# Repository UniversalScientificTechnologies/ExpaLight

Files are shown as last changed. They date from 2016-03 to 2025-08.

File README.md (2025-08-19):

 [Facebook](https://www.facebook.com/expalight)

# ExpaLight

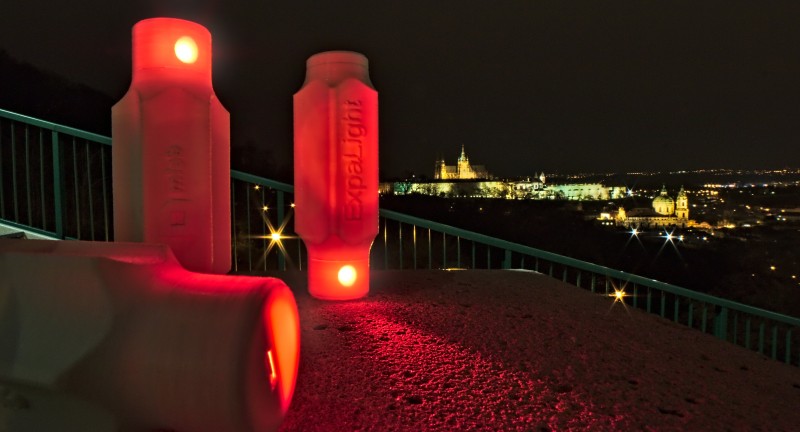
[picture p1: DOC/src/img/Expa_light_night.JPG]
ExpaLight 2017


**ExpaLight** is a red LED flashlight powered by a supercapacitor, designed especially for astronomical observations. The project originated for use during observation nights at summer astronomical schools at the observatory. Thanks to its robust and open-source design, ExpaLight is suitable for both amateur and professional users.

## Technical Parameters

| Parameter | Value |
| --- | --- |
| Stored energy | 350 J |
| Light duration | \~10 h |
| Charging time | < 50 s (typ.), max. 2 min |
| Charging indication | Green LED off at 80% voltage |
| Charging interface  | MicroUSB, ≤500 mA |
| Housing | 3D-printed PLA, durable, water-resistant |
| Light Source | High-efficiency red LED |

## Key Features

* **Supercapacitor energy storage** (350 J)
* **Light duration:** up to 10 hours
* **Fast charging:** typically under 50 seconds, max. 2 minutes from full discharge
* **Charging indication:** green LED turns off at \~80% voltage
* **Durable 3D-printed housing**, mechanically and water resistant
* **High-efficiency red LED**, optimized for dark adaptation of the human eye
* **No batteries needed**, USB charging (microUSB)
* **Open-source and repairable**

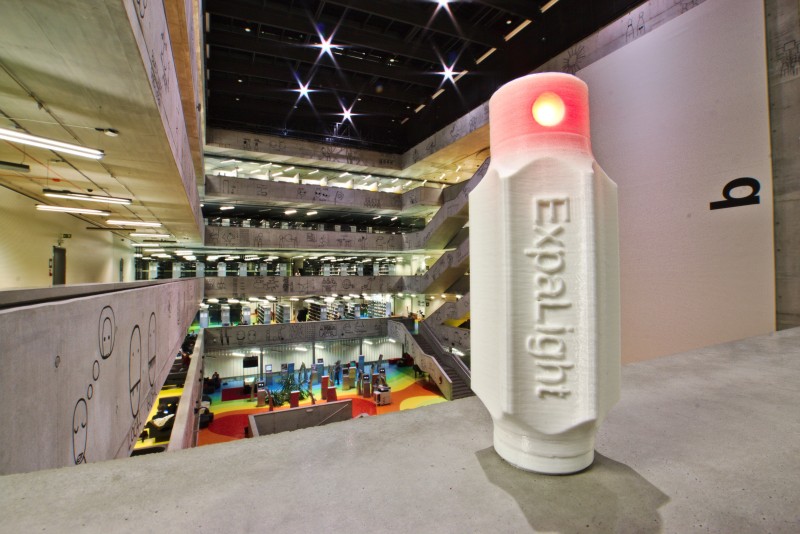
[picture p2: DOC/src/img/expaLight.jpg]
ExpaLight version 2017 ExpaLight


ExpaLight remains an active project despite repository inactivity. The design was made to withstand years of usage.

[Product manual – Czech version](/DOC/ExpaLight_navod.pdf)

## Why red light?

Astronomers use red light because it preserves the dark adaptation of the human eye, making it ideal for observing the night sky.

## Usage

* Can be placed **horizontally** (ideal for writing into observation logs)
* Can stand **vertically** with LED up or down
* Can be recharged while in use
* Works even when permanently connected to a charger

## Maintenance

* Clean with cloth and mild soapy water
* Do not wash under running water or immerse in liquids
* Avoid abrasive tools to prevent scratching the housing

## Frequently Asked Questions

**Do I need to switch it off?**
No. The flashlight has no mechanical switch. It shines until fully discharged, then you recharge it via USB.

**Why this shape?**
The hexagonal body prevents rolling, ensures stable positioning on surfaces, and supports versatile use (e.g. headlamp attachment in future).

**Can I leave it charging permanently?**
Yes. The electronics are designed to handle permanent connection safely.

**What happens if it is fully discharged?**
Nothing. Unlike battery-based lamps, the supercapacitor can be fully discharged without degradation.

**Can I use a mobile charger?**
Yes. Any standard microUSB charger (5V, ≤500 mA) or USB port will work. Some smart chargers may fail due to low current draw — in that case, use another charger.

## Availability

You can purchase ExpaLight at [Tindie](https://www.tindie.com/products/10265/) or contact us directly at **[sale@ust.cz](mailto:sale@ust.cz)**.

## Contributions

ExpaLight is an open-source hardware project. Suggestions and improvements are welcome! Please open an issue in the [GitHub tracker](https://github.com/UniversalScientificTechnologies/ExpaLight/issues).

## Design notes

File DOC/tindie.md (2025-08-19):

ExpaLight is a **supercapacitor-powered red LED flashlight** designed for astronomy, astrophotography, stargazing, and night-time outdoor activities. Its red light preserves night vision, allowing you to read star charts, write observation notes, or navigate in the dark without losing your dark adaptation. Unlike ordinary LED flashlights, ExpaLight is built to last a lifetime thanks to its supercapacitor technology.

#### Why did you make it?

Traditional flashlights powered by disposable or rechargeable batteries often fail in the field: they take a long time to recharge, lose capacity over time, and perform poorly in cold conditions. ExpaLight was created as a robust, reliable, and eco‑friendly alternative. With its quick‑charging supercapacitor, durable 3D‑printed body, and optimized red LED, ExpaLight is the perfect tool for astronomers and night-sky enthusiasts around the world.

#### What makes it special?

* **Supercapacitor energy storage** – no batteries, virtually infinite lifetime
* **Extended runtime** – up to 10 hours of continuous illumination
* **Ultra-fast charging** – under 50 seconds (max. 2 minutes from empty)
* **Universal charging** – works with any microUSB smartphone charger or computer USB port
* **Rugged design** – strong 3D‑printed chassis, splash-resistant and field‑tested
* **Optimized red light** – preserves night vision, ideal for astronomy and astrophotography
* **Cold‑resistant** – maintains performance even in the harshest freezing conditions on Earth, unlike standard batteries
* **Open-source and repairable** – hardware designed for modification, repair, and customization

Whether you are observing the Milky Way, taking long-exposure astrophotography, camping in the wilderness, or attending a star party, **ExpaLight gives you reliable red illumination without worrying about dead batteries.**

Its eco‑friendly design, virtually unlimited recharge cycles, and focus on astronomical use make ExpaLight more than just a flashlight – it’s a long-term tool for night-sky exploration.

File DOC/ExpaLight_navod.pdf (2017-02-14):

# Návod k použití

# ExpaLight

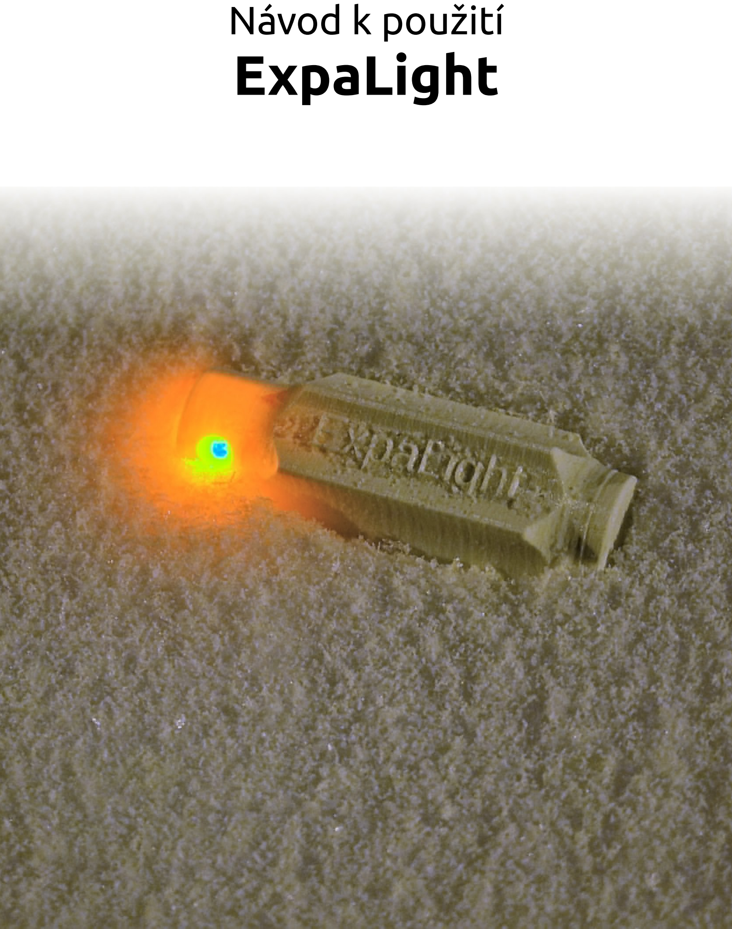
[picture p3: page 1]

## Základní Parametry

- Uložená elektrická energie: 350J
- Doba svícení: 10h
- Doba nabíjení: Při běžném používání do 50 s, maximálně 2 minuty (při úplném vybití)
- Indikace nabíjení zelenou LED diodou, dioda zhasíná při dosažení 80 % maximálního napětí na kondenzátoru.
- Mechanicky a vodě odolné pouzdro připravené pro další rozšíření
- Vysoce svítivá červená LED dioda ideální pro noční pozorování oblohy

## Nabíjení

Svítilnu ExpaLight lze nabít pomocí standardní USB micro nabíječky nebo pomocí USB micro kabelu z počítače. K nabíjení můžete použít stejnou nabíječku jako využívá většina dnešních mobilních telefonů. Nabíjecí proud je menší než 500mA, takže lze lampičku nabíjet i z libovolného USB 2.0 nebo vyšších verzí. V průběhu nabíjení uvnitř lampičky svítí zelená LED dioda. Při dosažení 80% pracovního napětí kondenzátoru indikační dioda zhasne.

Lampičku ale lze nechat připojenou k nabíječce trvale. Je to i vhodné pro dosažení maximální možné doby svícení.

## Údržba (Čištění)

Lampičku je třeba čistit hadříkem a mýdlovou vodou. Není možné čištění pod tekoucí vodou, nebo ponořením do vody.

## Možnosti použití

Lampička nabízí několik možností použití.
1) „na ležato”, která se hodí například při zapisování do pozorovacího deníku. Natáčením otočného obalu lze nastavit, jak daleko lampička bude svítit. V této poloze může být lampička také nabíjena.

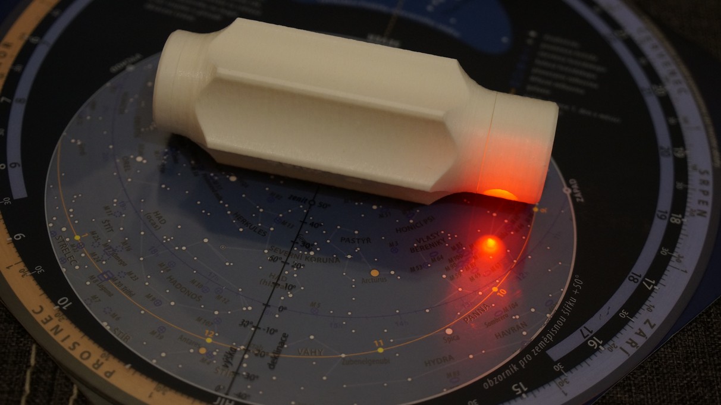
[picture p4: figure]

2) Další pozice jsou “na stojato”.
1) S LED diodou dole

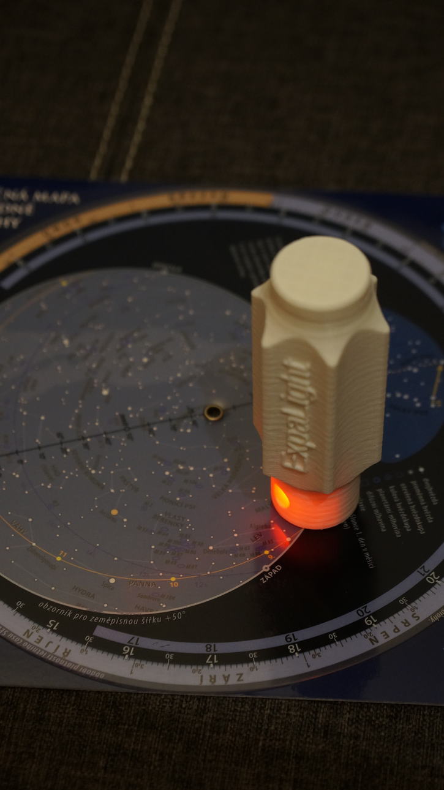
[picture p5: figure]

2) S LED diodou nahoře

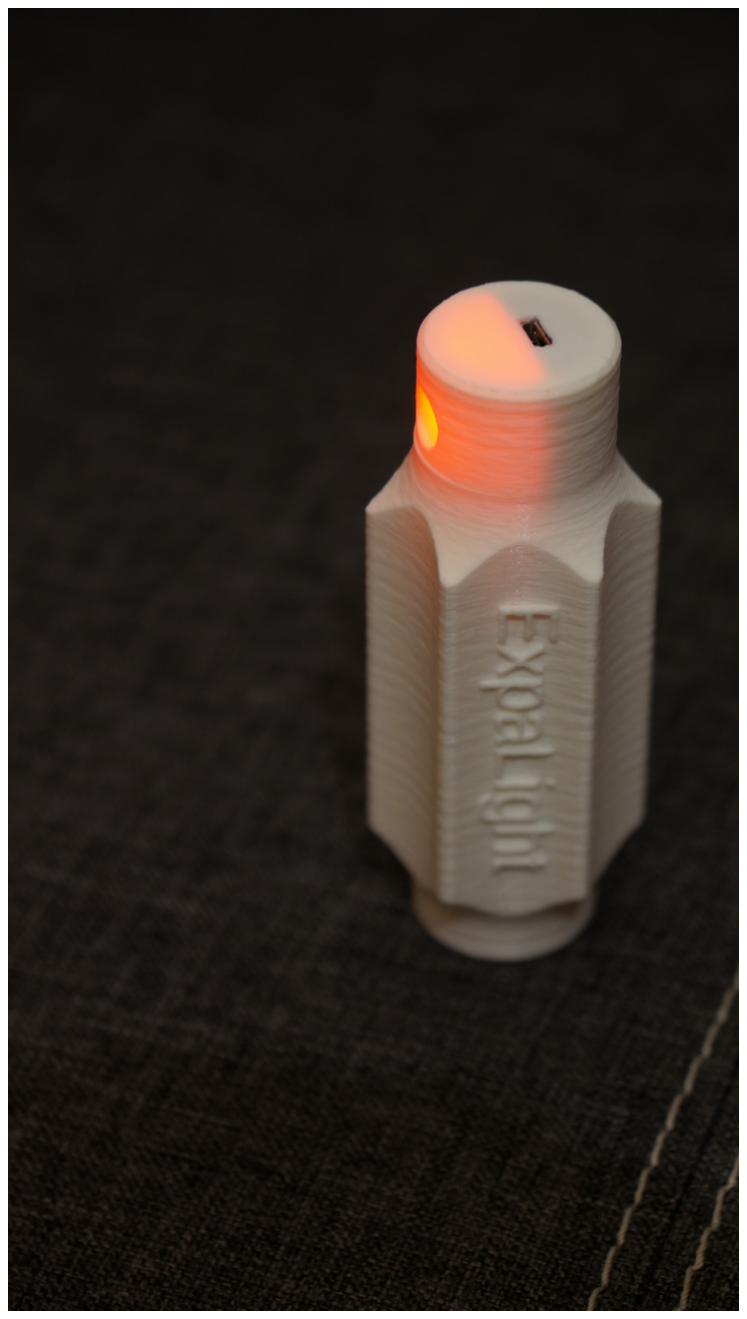
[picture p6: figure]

## Často kladené otázky:

### Proč lampička svítí červeně?

Kondenzátorová lampička ExpaLight byla navržena pro astronomické účely a proto svítí červeně. Červené světlo má nejmenší vliv na adaptaci oka na tmu a proto to je jediná použitelná barva při pozorování.

### Můžu si lampičku nabít nabíječkou na mobil?

Ano, lampičku lze nabít jakoukoliv nabíječkou, která má na svém konci USB micro. Nabíjecí napětí je 5V a proud maximálně 500mA.

### Jak lampičku vypnu?

Lampička nemá žádný vypínač. Je k tomu několik důvodů.
- Mechanická konstrukce je bez přítomnosti vypínače bytelnější.
- Lampička se při pozorování snáze najde.
- Kondenzátor se díky kvalitní elektronice neničí a má velký počet nabíjecích cyklů.
- Vybíjení kondenzátoru by se zpomalilo jen částečně.

### Proč byl zvolen takovýto tvar svítilny?

Tvar ExpaLight vychází ze zkušeností s astronomickým pozorováním. Tvar šestiúhelníku byl zvolen proto, aby se minimalizovalo kutálení po pozorovacím deníku. Své opodstatnění má také směr svitu led diody do strany, aby bylo možné mít lampičku položenou na straně papíru a nezabírala spoustu nevyužitelného místa. Při návrhu tohoto designu bylo myšleno především na pevnost celé konstrukce.

### Proč je elektronika tak složitá?

Elektronika lampičky by mohla být mnohem jednodušší, ale při testech takové lampičky se ukázalo spousta negativních vlivů. Například velmi pomalé nabíjení nebo extrémní špičkové proudy. Použití specializovaných součástek nám umožnilo zkombinovat všechny výhody kondenzátorů - rychlé nabíjení s maximálním proudem, které umí dodat běžný USB port nebo nabíječka na mobil.

### Jaké provozní podmíky ExpaLight vyžaduje?

Díky použití kondenzátorů opadá ztráta kapacity při nízkých teplotách. Teplota prostředí na dobu svitu má minimální následky. Lampička by tak měla fungovat ve většině pozorovacích podmínek.

### Existuj pro ExpaLight nějaké další příslušenství?

Zatím ne, ale díky tomu, že ExpaLight je open-source projekt a všechen hardware (mimo elektroniky) je vytisknut na 3D tiskárně, tak není problém udělat další příslušenství. Například je v plánu vytvořit držák pro lampičku, který bude použitelný jako čelovka.

### Můžu lampičku provozovat stále zapojenou v nabíječce?

Ano, lampička i v tomto stavu svítí a díky použití kvalitní elektroniky nedochází k jejímu ničení.

### Co se stane, když lampičku ExpaLight nechám úplně vybít?

Nic, díky použití kondenzátorů lze lampičku plně vybít bez jakýchkoliv následků na snížení kapacity. Jako v případě některých akumulátorů.

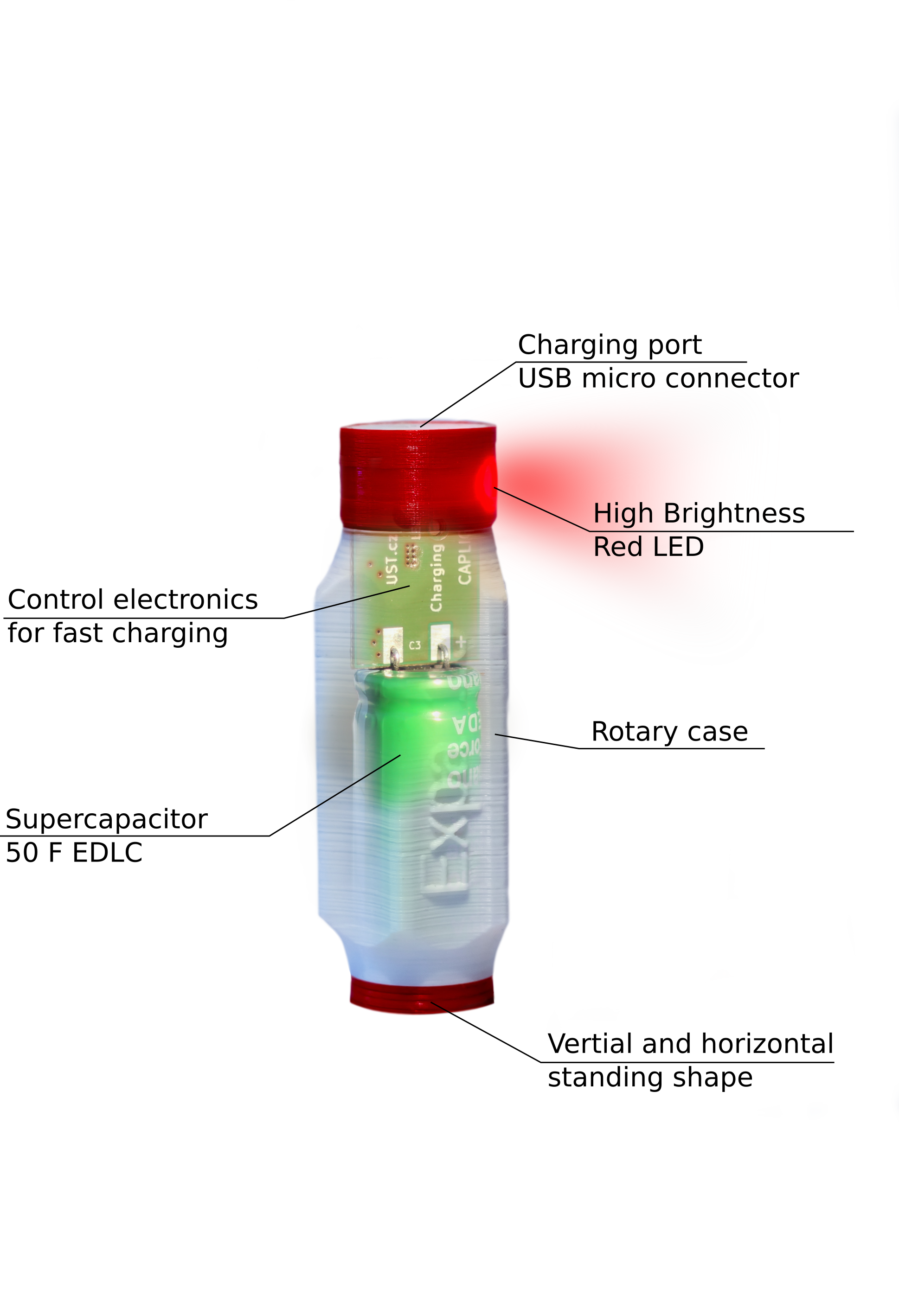
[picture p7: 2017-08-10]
DOC/describe.en.png

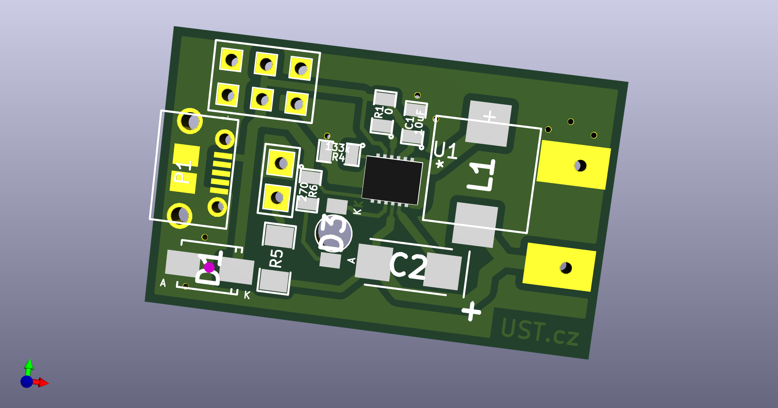
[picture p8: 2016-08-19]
DOC/src/img/CAPLIGHT01B_PCB_Bottom.png

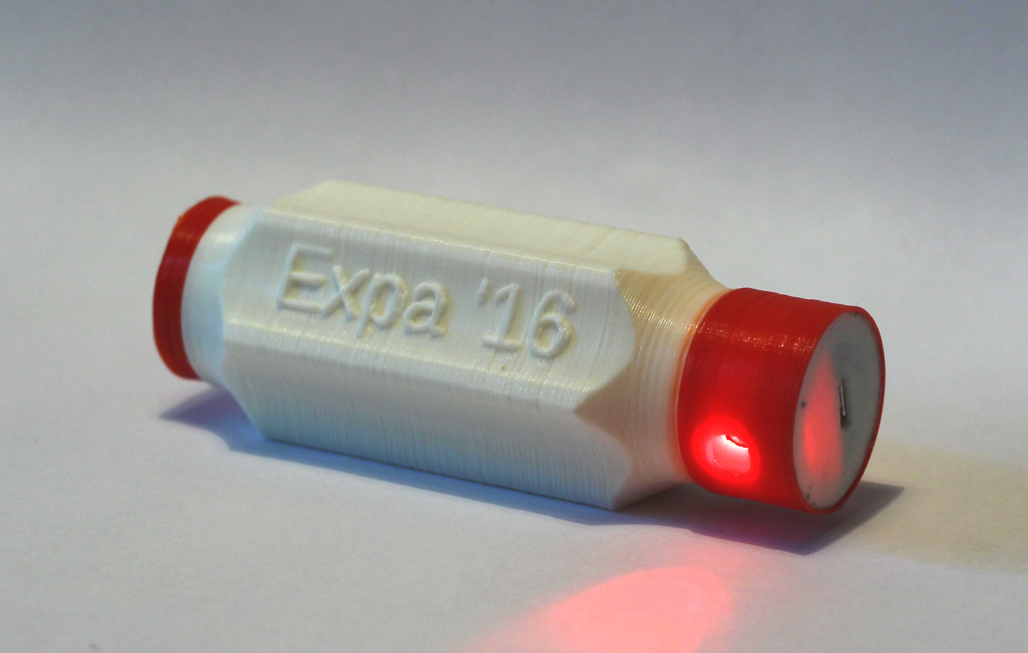
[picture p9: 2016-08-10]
DOC/src/img/Expa_light16.JPG

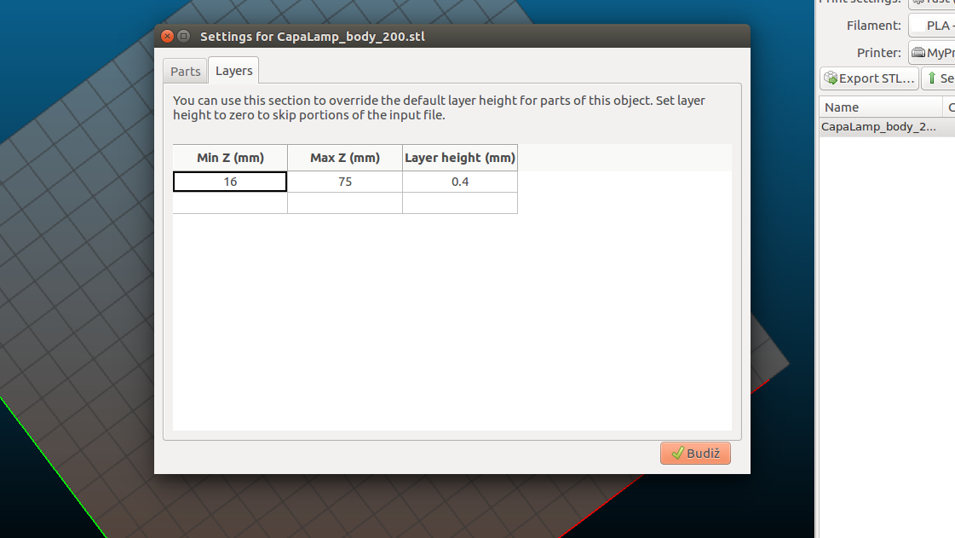
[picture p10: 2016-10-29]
render/cfg/slic3r/body-nastaveni-2.png

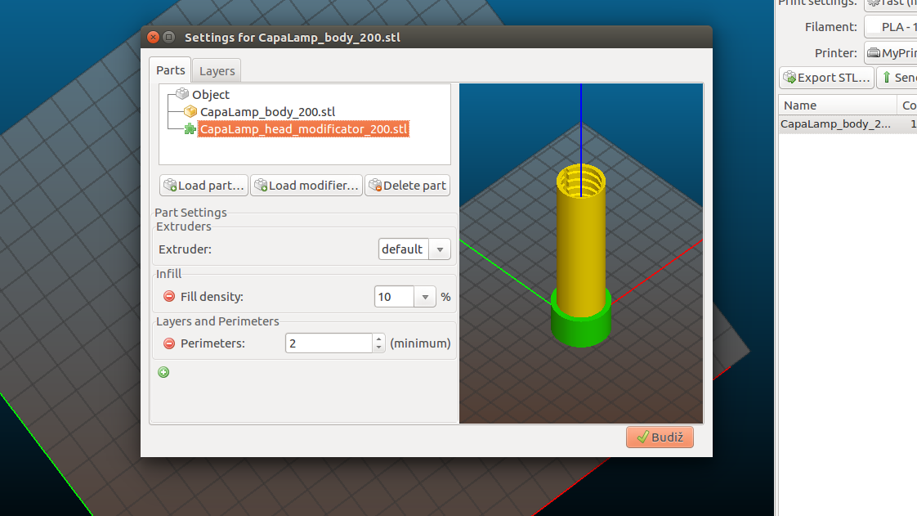
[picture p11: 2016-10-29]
render/cfg/slic3r/body-nastaveni-1.png

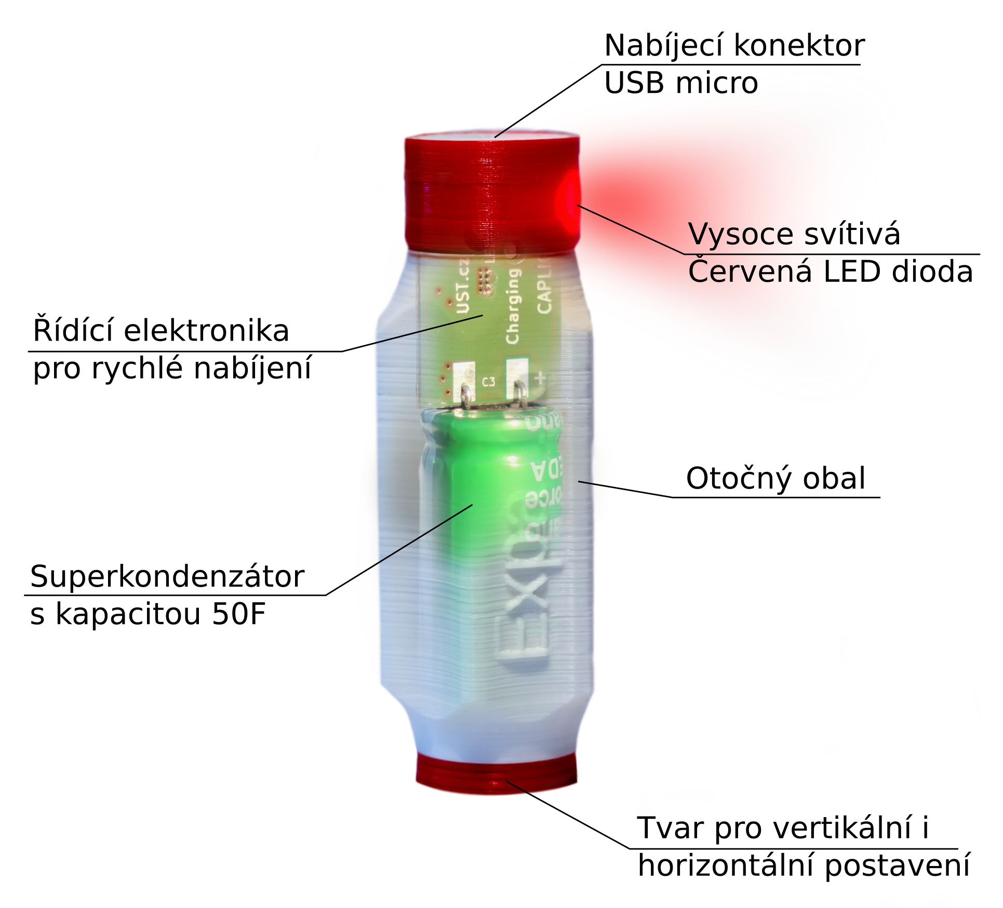
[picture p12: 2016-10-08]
DOC/out_render.png

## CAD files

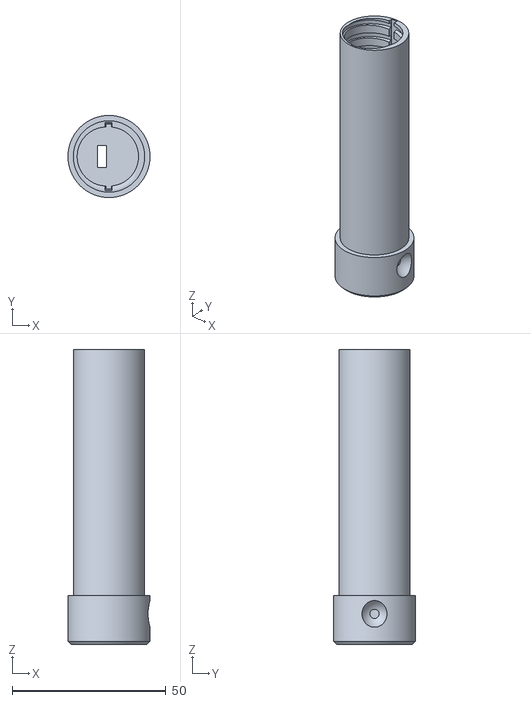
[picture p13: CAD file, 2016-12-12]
render/CapaLamp_body.stl
26.7 x 26.7 x 96.0

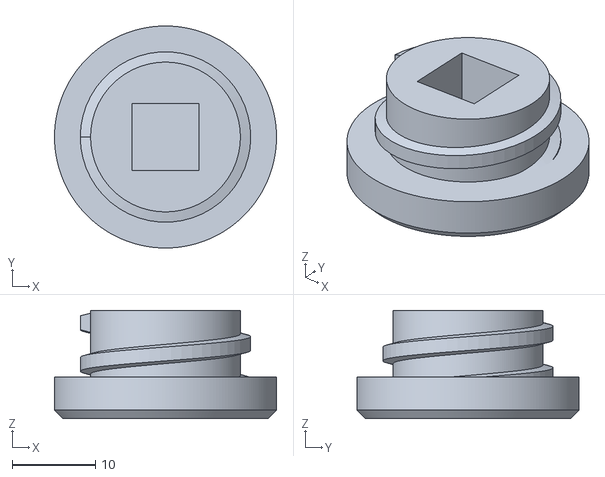
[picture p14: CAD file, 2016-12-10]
render/CapaLamp_cap.stl
26.7 x 26.7 x 13.0

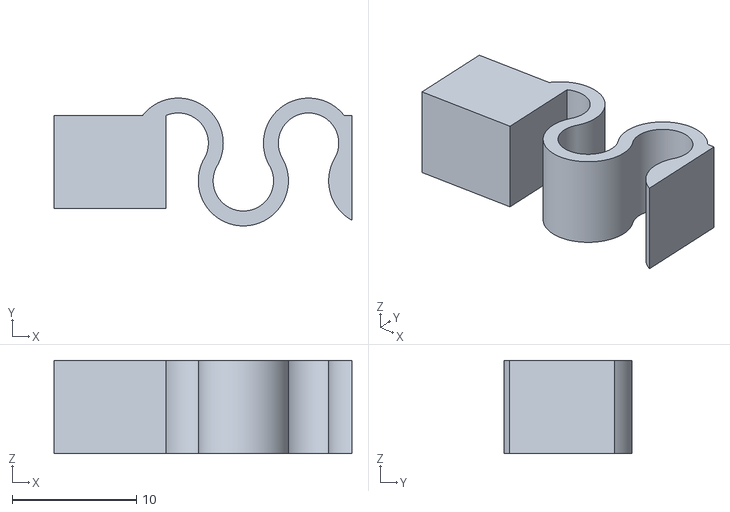
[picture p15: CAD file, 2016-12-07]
render/CapaLamp_spring.stl
24.0 x 10.3 x 7.50

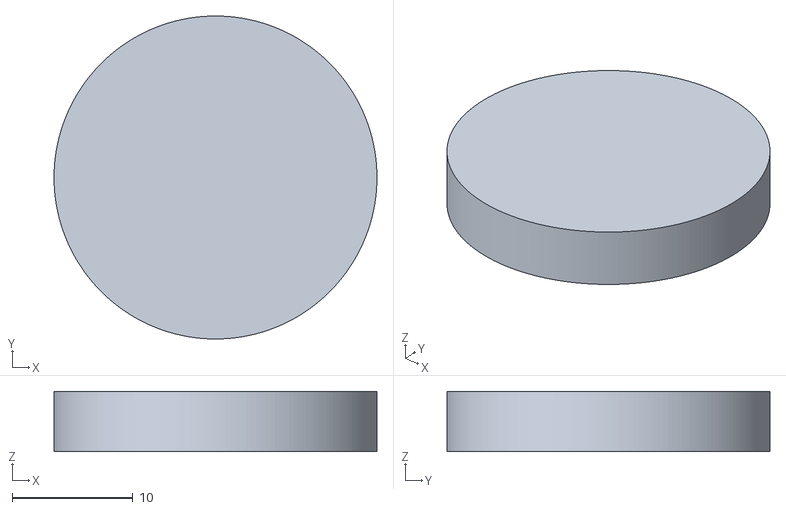
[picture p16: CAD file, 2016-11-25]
render/CapaLamp_cap_modificator.stl
26.7 x 26.7 x 5.00

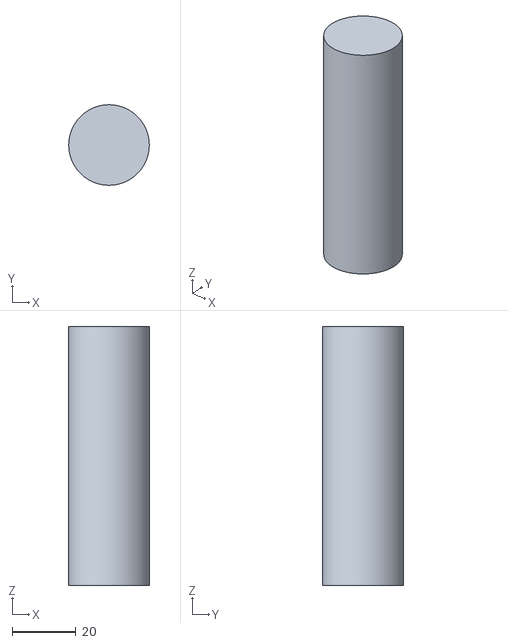
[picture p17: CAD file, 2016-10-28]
render/CapaLamp_body_thread_modificator_200.stl
25.2 x 25.2 x 81.0

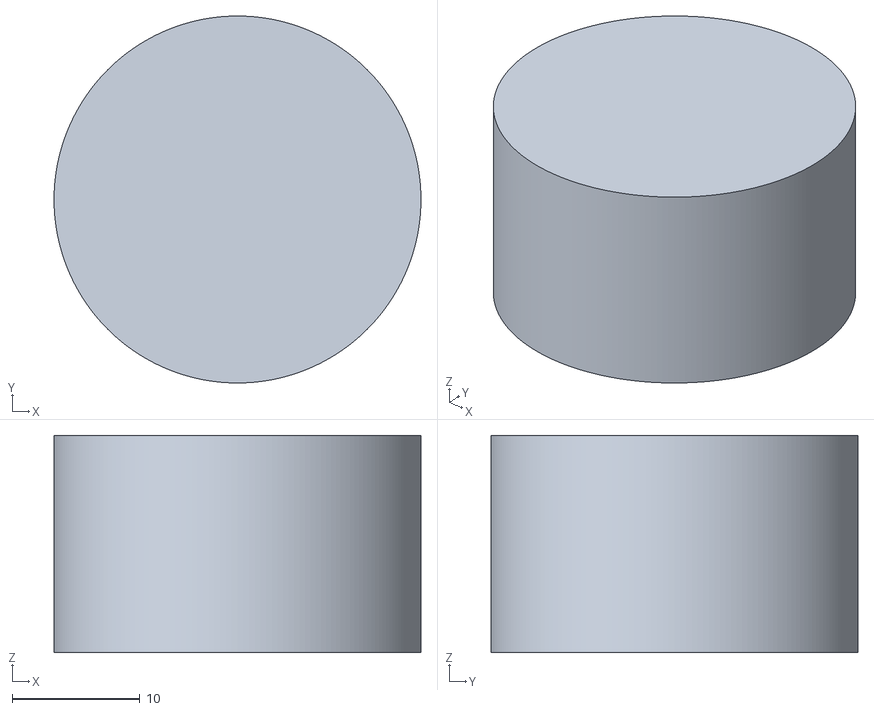
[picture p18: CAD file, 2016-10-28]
render/CapaLamp_body_head_modificator_200.stl
28.7 x 28.7 x 17.0

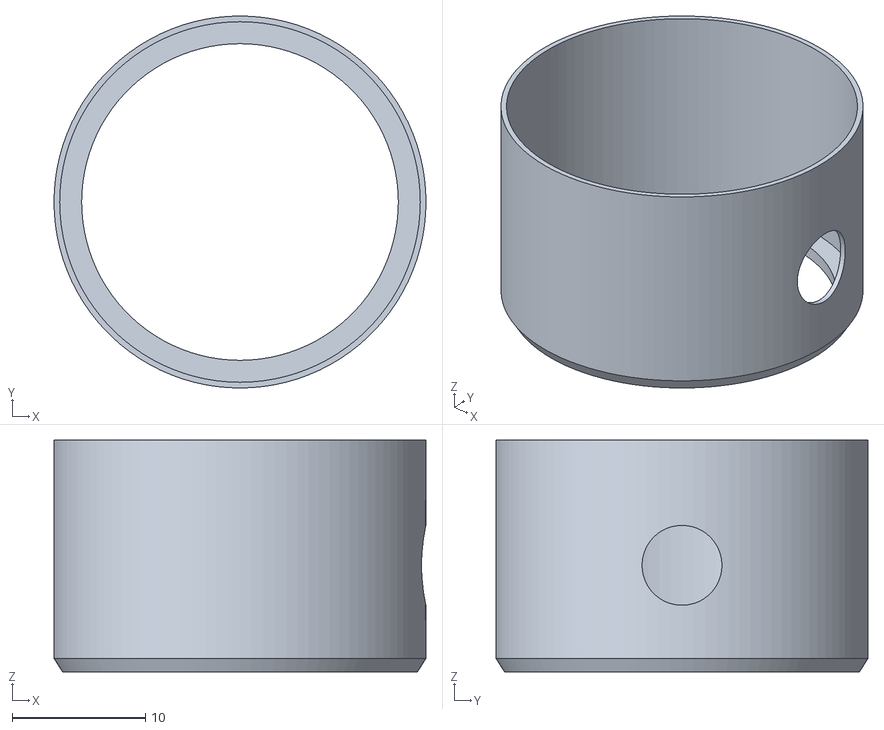
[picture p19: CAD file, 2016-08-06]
render/CapaLamp_Shield.stl
28.0 x 28.0 x 17.4

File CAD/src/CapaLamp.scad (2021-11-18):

//include <polyScrewThread_r1.scad>
use <Thread_Library.scad>
use <MLAB_logo.scad>
use <spring.scad>


$fn=200;

CLEAR = 0.05;
perimeter = 0.43;

text2 = "";

stena_hl = 2;
stena_hlava = 1; // spodni stena u usb
r_telo_in = 19.2/2;
r_telo_in_min = r_telo_in ;
r_telo_out = r_telo_in + stena_hl;

r_zavit = r_telo_in;

r_plast_in = r_telo_out + 0.5;
r_plast_out = r_plast_in + 8;

telo_vyska = 80;
telo_vyska_zavit = 10;

hlava_vyska = 15;
r_hlava_out = r_telo_out + 1.75;

led_dira = 3/2;
led_koule = 10;
led_koule_zanoreni = 3;
led_posun = 9;
led_mezera = 3;

sila_pcb = 1.8;
sila_prb_sirsi = sila_pcb + 0.5; // sirsi sila drazky pro snadnejsi zasunuti

m_pcb_offser = -0.15; //posun drazky pro pcb - kladna hodnota je posun k led
m_cap_offser = -0.75; //posun mista pro kondenzator - kladna hodnota je posun k led
m_pcb_bottom = 35;
m_pcb_top = m_pcb_bottom + 30;
m_pcb_width = 21;
m_pcb_width_sirsi = 22;
m_pcb_length = 30;

stena_vicko = 5;

INd = 50;


module body_r(){
    //cylinder(m_pcb_bottom,r_telo_in,r_telo_in);
    //translate([0,0,m_pcb_top]) #cylinder((telo_vyska-telo_vyska_zavit)-m_pcb_top,r_telo_in,r_telo_in);
    //translate([0,0,telo_vyska-telo_vyska_zavit-CLEAR]) cylinder(telo_vyska_zavit+10+CLEAR*2,r_telo_in_min+1,r_telo_in_min +1); // Nahradit závitem
	 //translate([0,0,telo_vyska-telo_vyska_zavit-CLEAR]) cylinder(telo_vyska_zavit+CLEAR*2,r_telo_in+1,r_telo_in+1); // Nahradit závitem

	translate([0,0,telo_vyska-telo_vyska_zavit-CLEAR-10]){
		trapezoidThread(
			length=telo_vyska_zavit+CLEAR+15,		// axial length of the threaded rod
			pitch=5, 						// axial distance from crest to crest
			pitchRadius=r_zavit, 		// radial distance from center to mid-profile
			threadHeightToPitch=0.5, 		// ratio between the height of the profile and the pitch
			profileRatio=0.5, 				// ratio between the lengths of the raised part of the profile and the pitch
			threadAngle=30,					// angle between the two faces of the thread
			RH=true, 						// true/false the thread winds clockwise looking along shaft, i.e.follows the Right Hand Rule
			clearance=0.1, 					// radial clearance, normalized to thread height
			backlash=0.1, 					// axial clearance, normalized to pitch
			stepsPerTurn=50 				// number of slices to create per turn
		);
	}


	translate([0,0,-hlava_vyska]){
				translate([0,0, 0]) cylinder(telo_vyska+hlava_vyska+CLEAR,r_telo_in_min,r_telo_in_min);

                translate([m_pcb_offser,0,0]){

				   #translate([(m_cap_offser-m_pcb_offser),0, 0]) cylinder(telo_vyska+hlava_vyska+CLEAR,r_telo_in_min,r_telo_in_min);
                    translate([-2*sila_pcb, -7/2, -stena_hlava-CLEAR]) cube([3, 7, stena_hlava+2*CLEAR]);                      // USB konektor díra

                    translate([-sila_pcb/2,-m_pcb_width/2, 0]) cube([sila_pcb, m_pcb_width, hlava_vyska+telo_vyska+CLEAR+10]);                                                                      // Drazka na PCB
                    translate([-sila_prb_sirsi/2,-m_pcb_width_sirsi/2, m_pcb_length+5]) cube([sila_prb_sirsi, m_pcb_width_sirsi, hlava_vyska+telo_vyska+CLEAR+10]);                // Drazka na PCB prechod
                    hull(){
                        translate([-sila_pcb/2,-m_pcb_width/2, m_pcb_length]) cube([sila_pcb, m_pcb_width, 0.1]);                                                   // Drazka na PCB
                        translate([-sila_prb_sirsi/2,-m_pcb_width_sirsi/2, m_pcb_length+5]) cube([sila_prb_sirsi, m_pcb_width_sirsi, 0.1]);                // Drazka na PCB prechod
                    }

                }
        // okenko pro led
                difference(){
                    union(){
                        rotate([0,90,0]) translate([-led_posun,0,0]) cylinder(r_hlava_out ,led_dira, led_dira);
                        translate([r_plast_out-led_koule_zanoreni, 0, led_posun]) resize(newsize=[1.5*led_koule,1*led_koule,1*led_koule]) sphere(led_koule);   // Koule (elipsoid) jako parabola pro led
                    }
                    //cylinder (hlava_vyska, r_telo_in+perimeter, r_telo_in+perimeter);
                }
                // translate([4.75,0, 5]) cylinder(150, 5, 5);
				//#intersection(){
					//translate([0,0, CLEAR]) cylinder(hlava_vyska+CLEAR,r_telo_in-CLEAR,r_telo_in-CLEAR);
					//union(){
					//	translate([-r_telo_in_min, -r_telo_in, 0]) cube([r_telo_in_min*2,r_telo_in*2, hlava_vyska]);
					//}
				//}
				//intersection(){
					translate([0,0, m_pcb_bottom+hlava_vyska-CLEAR]) cylinder(telo_vyska+hlava_vyska+CLEAR,r_telo_in-CLEAR,r_telo_in-CLEAR);
					//translate([-r_telo_in, -r_telo_in_min, m_pcb_bottom+hlava_vyska]) cube([r_telo_in*2,r_telo_in_min*2, m_pcb_top - m_pcb_bottom]);
				//}

			}

}

module body(){
	difference(){
		union(){
			translate([0,0,-hlava_vyska+CLEAR]) cylinder(hlava_vyska, r_hlava_out, r_hlava_out);
			translate([0,0,-hlava_vyska-stena_hlava+CLEAR]) cylinder(stena_hlava, r_hlava_out-1, r_hlava_out);
			cylinder(telo_vyska,r_telo_out,r_telo_out);
		}
		body_r();
	}
}


module head_modificator(){
    translate([0,0,-(hlava_vyska+stena_hlava)]) cylinder(hlava_vyska+stena_hlava+1, r_hlava_out+1, r_hlava_out+1);
}

module body_modificator(){
    translate([0,0,1]) cylinder(telo_vyska+1,r_telo_out+1,r_telo_out+1);
}

module cap(){
    zavit = r_zavit - 0.6;
    echo ("######################################");
    echo ("######################################");
    echo("---------------------------------- VICKO ----------------------------------------");
    echo ("Tloustka spodni steny vicka", stena_vicko);
    echo ("vyska zavitu vicka", (telo_vyska_zavit-CLEAR+5-stena_vicko));
    echo ("r zavitu", zavit);
    echo ("r vicka", r_hlava_out);
    echo ("######################################");
	difference(){
	union(){
		translate([0,0,telo_vyska_zavit-1]) cylinder(stena_vicko-1, r_hlava_out,r_hlava_out);
		translate([0,0,stena_vicko+telo_vyska_zavit-2]) cylinder(1, r_hlava_out,r_hlava_out-1);
		translate([0,0,1]) cylinder(telo_vyska_zavit, 18/2,18/2);
		intersection(){
            translate([0,0,stena_hlava])
                trapezoidThread(
                    length=telo_vyska_zavit-CLEAR+5-stena_vicko,		// axial length of the threaded rod
                    pitch=5, 						// axial distance from crest to crest
                    pitchRadius=zavit, 		// radial distance from center to mid-profile
                    threadHeightToPitch=0.5, 		// ratio between the height of the profile and the pitch
                                                    // std value for Acme or metric lead screw is 0.5
                    profileRatio=0.5, 				// ratio between the lengths of the raised part of the profile and the pitch
                                                    // std value for Acme or metric lead screw is 0.5
                    threadAngle=30,					// angle between the two faces of the thread
                                                    // std value for Acme is 29 or for metric lead screw is 30
                    RH=true, 						// true/false the thread winds clockwise looking along shaft, i.e.follows the Right Hand Rule
                    clearance=0.1, 					// radial clearance, normalized to thread height
                    backlash=0.1, 					// axial clearance, normalized to pitch
                    stepsPerTurn=50 				// number of slices to create per turn
                );
			cylinder(telo_vyska_zavit,30,30);
		}
	}union(){
        translate([-4,-4,-1]) cube([8,8,telo_vyska_zavit]); // dira pro pruzinu
		//translate([0,0,-CLEAR]) cylinder(telo_vyska_zavit-stena_hl ,r_telo_in_min*3/4-1,r_telo_in_min*3/4-1);
        //translate([0,-8, telo_vyska_zavit-0.2]) rotate([0,0,0]) linear_extrude(height = 0.25) text("IP11", halign="center", valign="center", size=4 );
	}
	}
}




module plast(text1, text2){
	rotate([0,0,360/6/2]) difference(){
		translate([0,0,CLEAR]) cylinder(telo_vyska-2*CLEAR, r_plast_out, r_plast_out, $fn=6);
		cylinder(telo_vyska,r_plast_in, r_plast_in);
		for(a=[0:6]){
			rotate([0,0,a*(360/6)]) translate([0,r_hlava_out*2.375,0]) cylinder(100, r_hlava_out*1.25, r_hlava_out*1.25);
		}
		translate([0, 0, telo_vyska]) rotate_extrude(convexity=10) translate([r_hlava_out*2,0,0]) circle(r_hlava_out);
		translate([     0,   0,   0]) rotate_extrude(convexity=10) translate([r_hlava_out*2,0,0]) circle(r_hlava_out);
	}
    translate([r_plast_out-5-0.8,0,telo_vyska/2]) rotate([0,90,0]) linear_extrude(height = 2)  text(text1, halign="center", valign="center", size=8 );
    translate([-(r_plast_out-5)+1.2,0,telo_vyska/2]) rotate([0,90,180]) linear_extrude(height = 2) text(text2, halign="center", valign="center", size=8 );
		if (len(text2) == 0)
    translate([-r_plast_out+5+1.25,0,telo_vyska/2])
			rotate([0,90,180])
					scale([0.15,0.15,0.52])
							MLAB_logo_short();
}

module pruzinka(){
    lenght = 21;
    cube_lenght = telo_vyska_zavit-1;
    cube_size = 7.5;

    echo("delka kostky");
    echo(cube_lenght);
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

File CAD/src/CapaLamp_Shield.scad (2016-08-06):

$fn=100;


CLEAR = 0.05;
perimeter = 0.43;

text2 = "jmeno";

stena_hl = 2;
stena_hlava = 1; // spodni stena u usb
r_telo_in = 19.2/2;
r_telo_in_min = r_telo_in ;
r_telo_out = r_telo_in + stena_hl;

r_zavit = r_telo_in;

r_plast_in = r_telo_out + 0.1;
r_plast_out = r_plast_in + 8;

telo_vyska = 80;
telo_vyska_zavit = 10;

hlava_vyska = 15;
r_hlava_out = r_telo_out + 1.75;

led_dira = 3;
led_koule = 10;
led_koule_zanoreni = 3;
led_posun = 9;
led_mezera = 3;

sila_pcb = 1.8;
sila_prb_sirsi = sila_pcb + 0.5; // sirsi sila drazky pro snadnejsi zasunuti

m_pcb_bottom = 35;
m_pcb_top = m_pcb_bottom + 30;
m_pcb_width = 21;
m_pcb_width_sirsi = 22;
m_pcb_length = 30;

INd = 50;

module shield() {
    difference(){
        union(){
            cylinder (hlava_vyska+stena_hlava+0.4, r_hlava_out + 1*perimeter+0.2, r_hlava_out + 1*perimeter+0.2 );
            translate ([0, 0, -1]) cylinder (1, r_hlava_out, r_hlava_out + 1*perimeter+0.2);
        }
        cylinder (hlava_vyska+stena_hlava+1+CLEAR, r_hlava_out+0.2, r_hlava_out +0.2);
        translate ([0, 0, -1]) cylinder (2, r_plast_in+0.2, r_plast_in+0.2 );
        rotate([0,90,0]) translate([-hlava_vyska-stena_hlava + led_posun,0,m_pcb_width/2+perimeter]) cylinder(r_hlava_out ,led_dira, led_dira);
        }
}




translate ([0,0,0]) shield();

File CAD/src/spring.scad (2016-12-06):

/* Begin customizer.makerbot.com section. */

length = 20;
number_of_wiggles = 4;
// The portion of the circle that appears in each wiggle
angle = 210; // [180:360]
angle = 240;
// The width of the band of material
width = 1.5;
height = 8;
// Circles are n-gons.  Choose n
resolution = 100;

/* End customizer.makerbot.com section. */




module ring(outer, inner, h) {
  difference() {
    cylinder(h=h, r=outer);
    cylinder(h=h, r=inner);
  }
}

module arc_of_cylinder(r, h, angle /* angle must be <= 180 */) {
  half_angle = 90 - (angle / 2);
  difference() {
    cylinder(h=h, r=r);
    rotate(half_angle) translate([-r,0,0]) cube(size=r*2);
    rotate(-half_angle) translate([-r,0,0]) cube(size=r*2);
  }
}

module arc_of_ring(outer, inner, h, angle /* must be 180 <= angle <= 360 */) {
  difference() {
    ring(outer, inner, h);
    arc_of_cylinder(r=2*outer, h=h, angle=360 - angle);
  }
}

module spring4(length, n, angle /* must be 180 <= angle <= 360 */, width, height) {
  useful_intermediate_angle = 180 - angle / 2;
  echo(useful_intermediate_angle);
  path_radius = length / (2 * n * sin(useful_intermediate_angle));
  echo(path_radius);
  half_width = width / 2;
  inner = path_radius - half_width;
  outer = path_radius + half_width;  
  x_spacing = length / n;
  y_offset = length / (2 * n * tan(useful_intermediate_angle));
  epsilon = y_offset / 10000;   // Grr.
  adjusted_y_offset = y_offset - epsilon;
  union() for (i = [0 : n-1]) {
    translate([x_spacing * i, 0, 0])
      rotate([0,0,180 * i])   // mirror() works better
      translate([0, adjusted_y_offset, 0])
      arc_of_ring(outer, inner, height, angle);
  }
}

// With args from customizer.makerbot.com section above
//spring4(length, number_of_wiggles, angle, width, height, $fn=resolution);

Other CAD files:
render/dotaznik/lenka.stl
CAD/src/printplate/plast.scad
CAD/src/MLAB_logo.scad
CAD/src/Thread_Library.scad

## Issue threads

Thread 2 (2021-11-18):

A more efficient LED regulator

kaklik, 2021-11-18:
Aktuálně je proud LED vyřešen linearizačním rezistorem.  Pro zvýšení účinnosti a stabilizaci světelného toku během doby svícení by se hodilo najít účinnější regulátor proudu LED než aktuální linearizace resistorem.

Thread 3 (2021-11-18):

3D printed housing manufacturing

kaklik, 2021-11-18:
- Zvážit posunutí výřezu pro PCB tak, aby kondenzátor nemusel mít nožičky ohnuté mimo svojí osu.
- Zvážit vytvoření osazení pro LED na vnitřní straně obalu, které by snížilo možnost průniku vody okolo LED.

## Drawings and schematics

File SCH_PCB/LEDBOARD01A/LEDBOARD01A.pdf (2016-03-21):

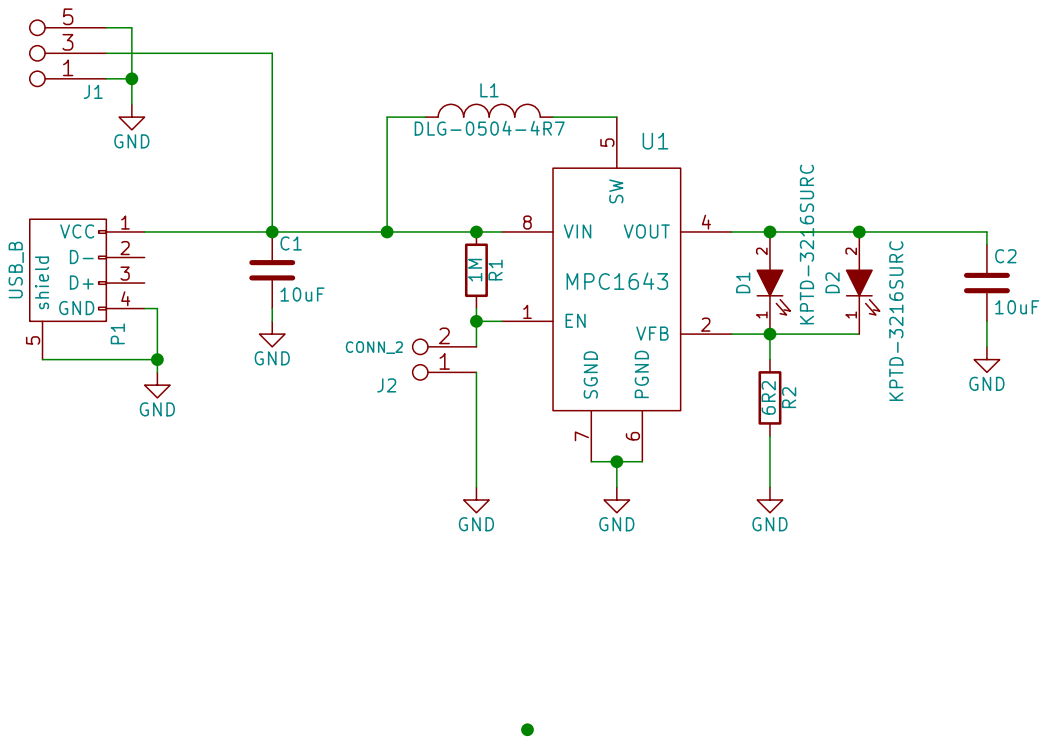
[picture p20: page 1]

Id: 1/1 Title: File: LEDBOARD01A.sch Sheet: /

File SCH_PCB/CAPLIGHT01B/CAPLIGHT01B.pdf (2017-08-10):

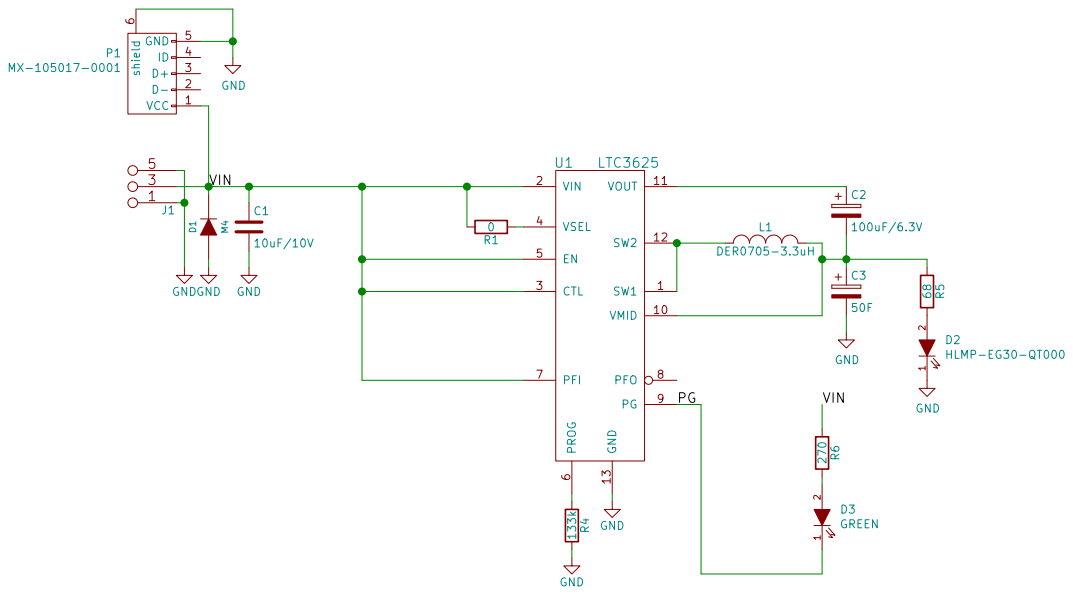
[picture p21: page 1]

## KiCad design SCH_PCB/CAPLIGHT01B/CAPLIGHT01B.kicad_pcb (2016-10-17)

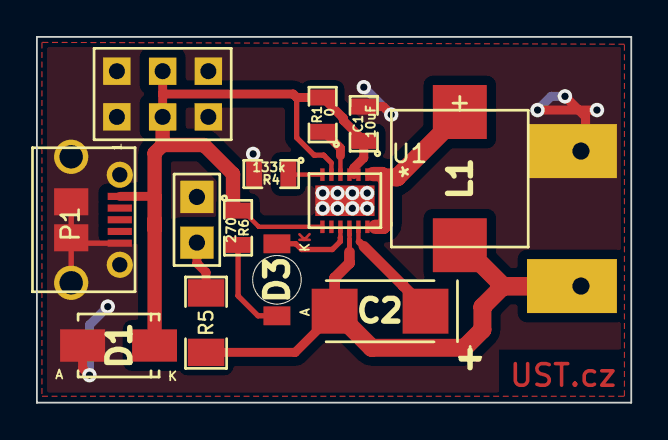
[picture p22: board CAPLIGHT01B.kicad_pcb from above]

Board: 2 copper layers, 33.0 x 20.3 mm, 14 parts (1 on the bottom side), 10 nets.

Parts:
C1: 10uF; SMD-0805
C2: 100uF; TantalC_SizeC_Reflow
C3: 50F; C_Radial_D18_L25_P7.5_BAT
D1: M4; SMA_Standard
D2: LED; Straight_1x02
D3: LED; LED_1206
J1: JUMP_3X2; Straight_2x03
L1: DER0705-3.3uH; DER0705
P1: USB_OTG; uUSB-B
R1: 0; SMD-0805
R4: 133k; SMD-0805
R5: 68; SMD-1206
R6: 270; SMD-0805
U1: LTC3625; DFN-12-1EP_3x4mm_Pitch0.5mm

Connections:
/PG: D3.1, U1.9
/VIN: C1.1, D1.2, J1.3, J1.4, P1.1, R1.2, R6.1, U1.2, U1.3, U1.5, U1.7
GND: C1.2, C3.2, D1.1, D2.1, J1.1, J1.2, J1.5, J1.6, P1.5, R4.2, U1.13
unnamed: C2.1, U1.11
unnamed: C2.2, C3.1, L1.2, R5.1, U1.10
unnamed: D2.2, R5.2
unnamed: D3.2, R6.2
unnamed: L1.1, U1.1, U1.12
unnamed: R1.1, U1.4
unnamed: R4.1, U1.6

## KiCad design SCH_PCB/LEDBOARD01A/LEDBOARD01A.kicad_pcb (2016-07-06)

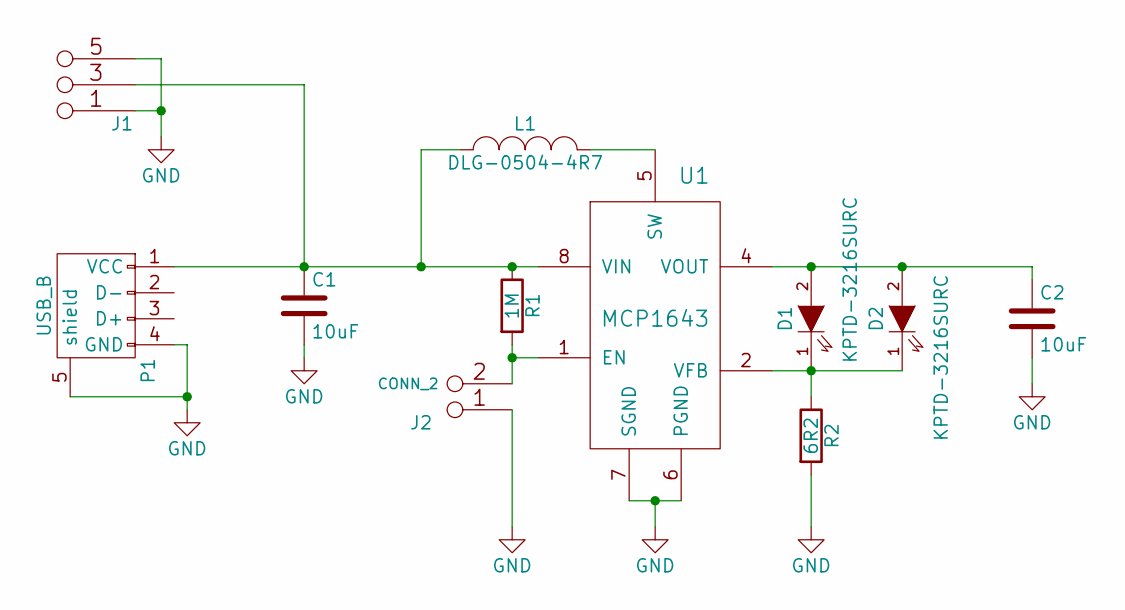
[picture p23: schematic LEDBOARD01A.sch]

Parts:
C1, C2: 10uF; SMD-0805
D1, D2: KPTD-3216SURC; LED_1206
J1: JUMP_3X2; Straight_2x03
J2: CONN_2; Straight_1x02
L1: DLG-0504-4R7; DLG0504
P1: USB_B; uUSB-B
R1: 1M; SMD-0805
R2: 6R2; SMD-0805
U1: MCP1643; MSOP-8_3x3mm_Pitch0.65mm

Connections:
GND: C1.2, C2.2, J1.1 (2), J1.2, J1.5 (6), J1.6, J2.1, P1.4 (GND), P1.5 (shield), R2.2, U1.6 (PGND), U1.7 (SGND)
unnamed: C1.1, J1.3 (4), J1.4, L1.1, P1.1 (VCC), R1.1, U1.8 (VIN)
unnamed: C2.1, D1.2 (A), D2.2 (A), U1.4 (VOUT)
unnamed: D1.1 (K), D2.1 (K), R2.1, U1.2 (VFB)
unnamed: J2.2 (PM), R1.2, U1.1 (EN)
unnamed: L1.2, U1.5 (SW)

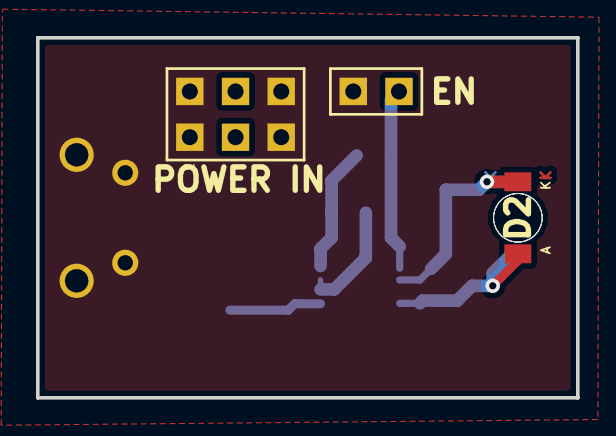
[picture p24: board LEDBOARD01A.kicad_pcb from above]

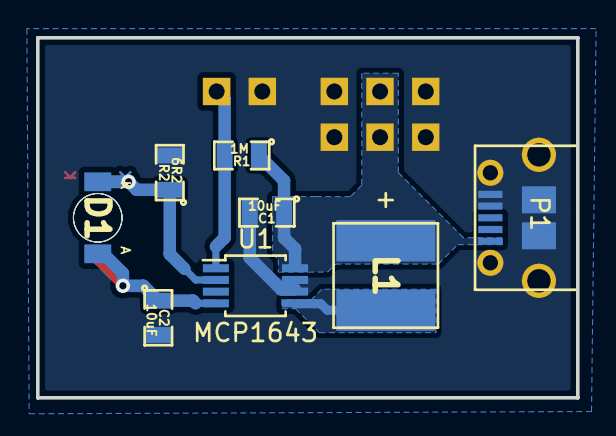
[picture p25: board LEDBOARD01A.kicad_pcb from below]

Board: 2 copper layers, 30.0 x 20.0 mm, 11 parts (8 on the bottom side), 6 nets.

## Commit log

2016-03-08 Init - Existing model
    [CapaLamp.scad, CapaLamp.stl, CapaLamp2_model.stl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]
2016-03-08 Dual capacitor version -- old is in another branch
    [CapaLamp.stl, CapaLamp2_model.stl, CapaLamp2_model_opened.stl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]
2016-03-09 light body
    [CapaLamp.scad, CapaLamp_body.stl]
2016-03-09 add case
    [CapaLamp.scad]
2016-03-10 parabolic led view, PCB spacers, PCB space
    [CapaLamp.scad]
2016-03-10 New Thread_lib
    [CapaLamp.scad, CapaLamp_body_200.stl, Thread_Library.scad]
2016-03-21 Creation PCB
    [LEDBOARD01A.kicad_pcb, LEDBOARD01A.sch]
2016-04-27 move .scad files to /CAD/
    [CapaLamp.scad, Thread_Library.scad, polyScrewThread_r1.scad]
2016-06-28 SuperCap module with led
    [CAPLIGHT01A.csv, CAPLIGHT01A.kicad_pcb, CAPLIGHT01A.sch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]
2016-07-01 nová verze
    [CAPLIGHT01A.kicad_pcb, SUPERCAP01A.csv, SUPERCAP01A.kicad_pcb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]
2016-07-02 Second capacitor SMD pad
    [CAPLIGHT01A.kicad_pcb, CAPLIGHT01A.sch]
2016-07-02 pcb labels
    [CAPLIGHT01A.csv, CAPLIGHT01A.kicad_pcb]
2016-07-03 only for ExpaLight
    [CAPLIGHT01A.kicad_pcb, CAPLIGHT01A.sch]
2016-07-03 layout edit
    [CAPLIGHT01A.kicad_pcb, CAPLIGHT01A.sch]
2016-07-03 tracks width
    [CAPLIGHT01A.kicad_pcb]
2016-07-03 pdf update
    [CAPLIGHT01A.sch]
2016-07-06 New charge indicating LED added. Manufacturing files generated.
    [CAPLIGHT01A.kicad_pcb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]
2016-07-06 Capacitor graphics removed.
    [CAPLIGHT01A.kicad_pcb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]
2016-07-06 Silkscreen updated.
    [CAPLIGHT01A.kicad_pcb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]
2016-07-21 case edist
    [CapaLamp.scad, CapaLamp_body_200.stl]
2016-07-21 printable parts
    [CapaLamp.scad, CapaLamp.stl, CapaLamp_body_200.stl]
2016-07-21 script for rendering
    [CapaLamp.scad, results.tsv]
2016-08-06 printed case update
    [CapaLamp.scad, CapaLamp_Shield.scad, CapaLamp_Shield.stl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]
2016-08-09 add photo
    [CapaLamp_cap.stl]
2016-08-10 Components values in schema changed to real values populated on PCBs. A photo added to the readme file.
    [CAPLIGHT01A.sch]
2016-08-19 Improved PCB layout for easier manufacturing.
    [CAPLIGHT01B.csv, CAPLIGHT01B.kicad_pcb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]
2016-10-08 edit model size
    [CapaLamp.scad, CapaLamp_body_200.stl, CapaLamp_cap_200.stl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]
2016-10-10 add hole to cap
    [CapaLamp.scad, CapaLamp_cap_200_5mm.stl]
2016-10-14 Opravy výrobní data
    Generována nová data. Zvětšen otvor pro C 50F.
    [CAPLIGHT01B-B.Cu.gbr, CAPLIGHT01B-B.Mask.gbr, CAPLIGHT01B-B.SilkS.gbr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]
2016-10-17 cap with spring
    [CapaLamp.scad, CapaLamp_cap_200_5mm.stl, CapaLamp_spring.stl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]
2016-10-21 Supplementing identification devices
    [CAPLIGHT01B.csv]
2016-10-28 add new files
    [CapaLamp.scad, CapaLamp_body_modificator_200.stl, CapaLamp_cap_200.stl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]
2016-11-25 new render
    [CapaLamp_cap_200_square_5mm.stl, CapaLamp_cap_200_square_5mm_v2.stl, CapaLamp_cap_modificator.stl]
2016-11-30 clean repository
    [CapaLamp.stl, CapaLamp_Shield_2p.stl, CapaLamp_body.stl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]
2016-12-06 add spring
    [CapaLamp.scad, CapaLamp_spring.stl, spring.scad]
2016-12-06 spring edit, squarly end
    [CapaLamp_cap.stl, CapaLamp_cap_200_square_5mm_v2.stl, CapaLamp_spring.stl]
2016-12-06 source file update
    [CapaLamp.scad]
2016-12-06 spring - remove sharp edge
    [CapaLamp.scad, CapaLamp_spring.stl]
2016-12-07 shorter spring
    [CapaLamp.scad, CapaLamp_cap.stl, CapaLamp_spring.stl]
2016-12-10 better edges, bigger hole for led.
    [CapaLamp.scad, CapaLamp_body.stl, CapaLamp_cap.stl]
2016-12-12 dira u led d=3mm, posun PCB smerem od LED, vetsi misto na C
    [CapaLamp.scad, CapaLamp_body.stl, CapaLamp_body_200.stl]
2016-12-12 new spacing
    [CapaLamp.scad, CapaLamp_body.stl]
2017-08-10 Documentation updated, english texts improved. Idicator LED changed to green in schematics.
    [CAPLIGHT01B.sch]
2017-08-10 PDF plot of schematics updated.
2021-11-18 Update renders.
    [CapaLamp.scad, plast.scad]
